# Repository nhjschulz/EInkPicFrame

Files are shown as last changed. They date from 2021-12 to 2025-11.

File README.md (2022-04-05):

# EInkPicFrame

The project builds an electronic picture frame using a 7 color E-Ink display.
It updates after an adjustable time period by reading images from an SD-Card.
The frame is powered from a battery and mimics a real picture frame by requiring
no power cable or a backlight. The software and hardware implements various power
saving methods to run for a long time without recharging.  

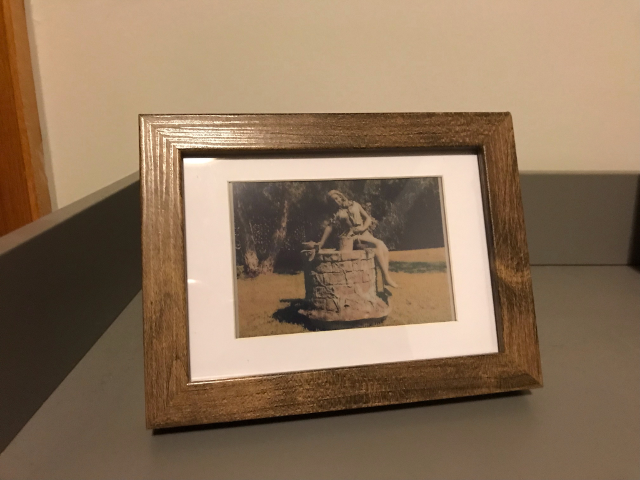
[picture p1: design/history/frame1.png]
Frame One


This is a hobbyist project. I have >20 years background in software development,
but lack the electronic engineering background. I'm using this project to
clear the fog in these mysterious regions below a HAL software layer. The project
therefore includes a hardware design as well.

## Requirements

A set of project requirements is collected here: [Requirements](design/Requirements.md)

## Concept

Block diagram of the system:

Context

## Used Tools

The project is build using open source tools only. All of them are available for free. The following table shows the tools and versions used during development:

|Tool | Usage | Version | Link |
|---|---|---|---|
| Visual Studio Code | Editor and IDE | 1.63.2 | [https://code.visualstudio.com/](https://code.visualstudio.com/) |
| PlatformIO | Software build tools | 5.2.4 | [https://platformio.org/](https://platformio.org/) |
| Python | Script programming | 3.10.1 | [https://www.python.org/](https://www.python.org/) |
| GIMP | Image Manipulation | 2.10.30 | [https://www.gimp.org/](https://www.gimp.org/) |
| ImageMagick | Image Manipulation | 7.1.0 | [https://imagemagick.org/](https://imagemagick.org/) |
| GIT | Version Control | 2.19 | [https://git-scm.com/](https://git-scm.com/) |
| KiCad EDA | Hardware Design | 5.1.12 | [https://www.kicad.org//](https://www.kicad.org/) |

## Software Architecture

The implemented software architecture design is shown on the [Software Architecture](design/SwArchitecture.md) page.

## Hardware

The system is assembled using the following parts: [Partlist](design/Parts.md).

A description of the PCB developed for this project is described
here: [PCB](design/hardware.md).

## Image Generation

The images to show on the frame must be in a special raw format. The process to generate this format is
described on the [ImageConverter](imgconverter/howto.md) page.

## File System

The SD Card must be formated using a FAT file system. The software
expects a folder with the name "epd" on it. This folder contains
the following data:

      [epd]
       |---- [err]
       |---- [img]
       |---- epd.cfg

* The folder "err" holds error images that are displayed in case
  of a problem, like "low battery".
* The folder img holds your images in epd format.
* The file epd.cfg are the parameters for the display. See
  [Parameter File](./design/Parameter.md) for instructions to
  create it.

An example file system can be copied from the example
[File System](./design/FileSystem) folder.

## Prototype Progress

* 2021-12-11: System functional on breadboard (V1 hardware)
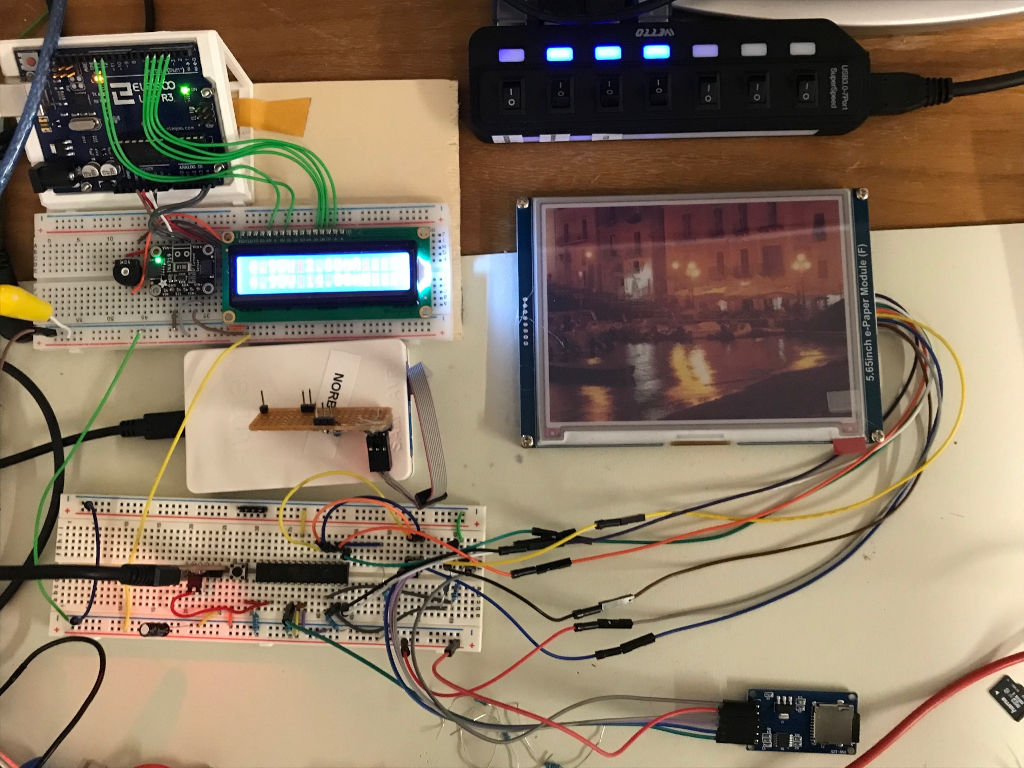
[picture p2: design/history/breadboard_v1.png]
breadboard
  

* 2021-01-22: V1 PCBs arrived and work
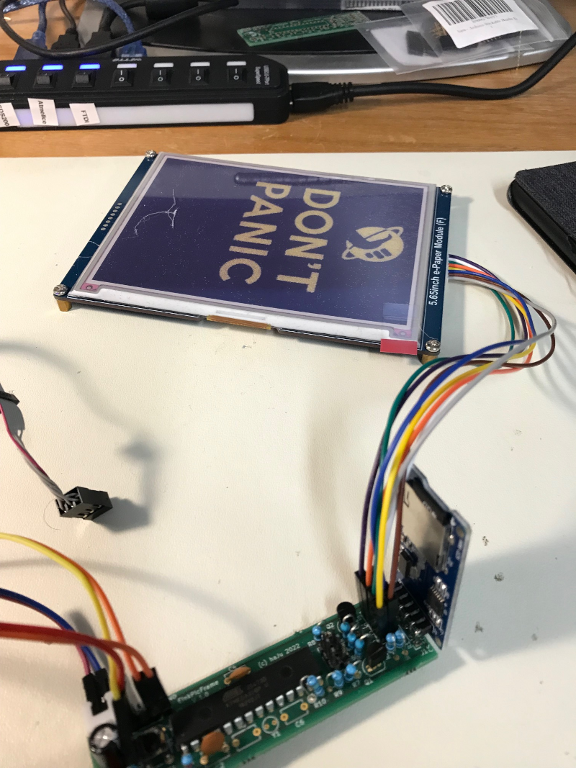
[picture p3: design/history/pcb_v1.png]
PCBv1
  

* 2022-02-01: First frame starts long run test in the living room
  Frame One

  Back side:

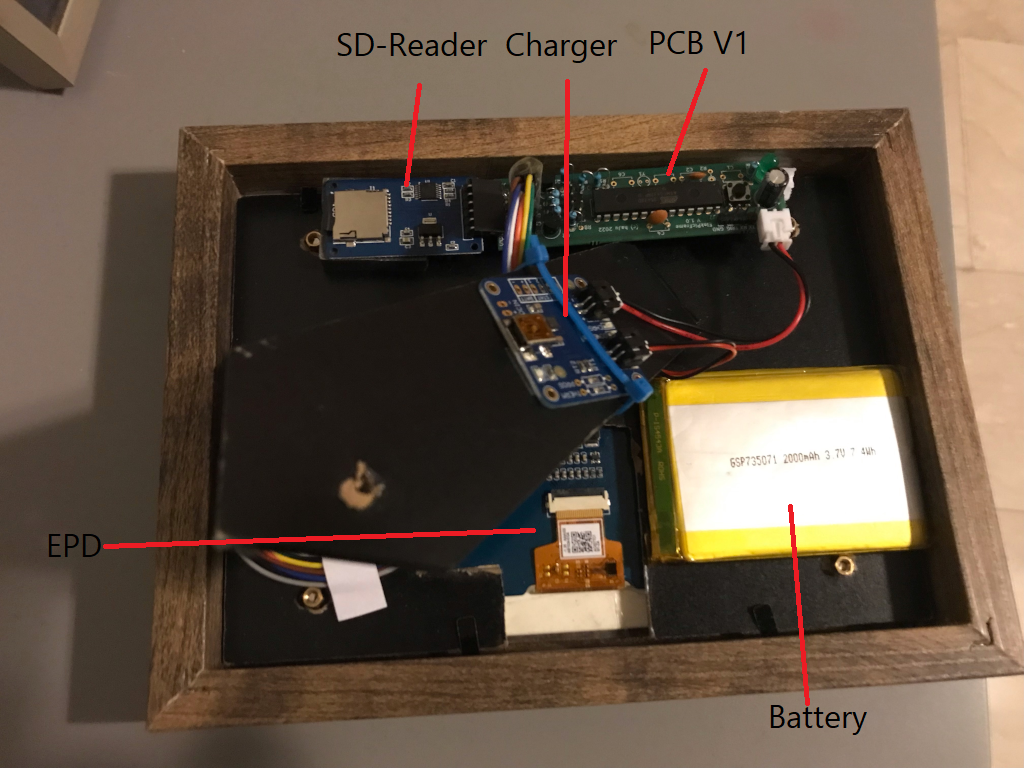
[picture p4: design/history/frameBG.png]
Back


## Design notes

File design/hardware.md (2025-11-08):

# EInkPicFrame Hardware

This page describes the hardware developed for the EinkPicFrame Project.
The current board revision is 1.1. It got designed using KiCAD. The
schematic and pcb project files are in the [hardware](../hw) folder.

The board is deliberately designed to be as small as possible. It's main
purpose is to hide inside a picture frame. It may even get smaller using
SMD parts. I avoided them as I'm realistic regarding my soldering skills.

## Microcontoller AVR 328PU

The heart of the PCB is the AVR 328PU microcontroller. It gives access to
the following capabilities:

* SPI is used for reading from SD-Card, writing to EPD and ISP programming.
* UART TX/RX - Only TX for debug prints is used, RX input is ignored
* A 32.768 kHz watch crystal on the XTAL pins drives Timer2 to wakeup
  the controller from power safe mode.
* ADC voltages - Reference voltage uses the recommended wiring with a capacitor
  and inductor. It is used for measuring the input voltage for low battery
  indication.
* A reset button is connected to restart the system without power cycling.
* PORT C pins are available on a header, but currently unused. They are for
  future extensions.

The pin usage is detailed on the [Pins](Pins.md) page.

## Connectors

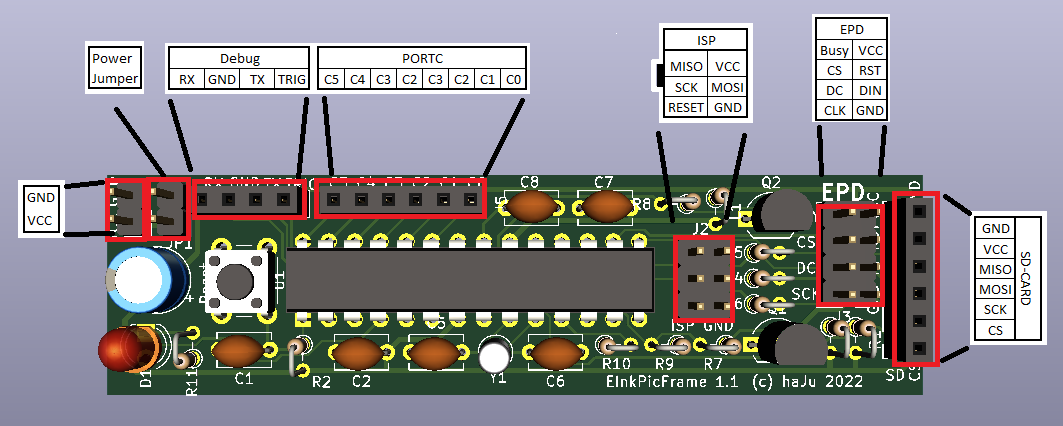
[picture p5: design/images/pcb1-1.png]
Board Connector


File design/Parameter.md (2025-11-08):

# Parameter

EPD supports a parameter file to influence its behavior.
The parameter file is optional. Internal defaults are used
if no parameter block is present in the file system.

## Parameter File

The software expects the parameter file at the following location:

    /epd/epd.cfg

The file is a binary file in the format defined below.
A binary file method was chosen to unburden the microcontroller from
text parsing needs. EPD also offers no user interface for editing
parameter. Producing the parameter set on a PC and store it in the file
system is therefore the easiest solution.

## Paramter File Layout

The contents of the parameter file is a short header, followed by a
sequence of 16 bit values (the parameters) in little endian byte
order (same as on a PC).

### Parameter Header Layout

The parameter header is a sequence of 6 bytes defined below:

             0x00         0x01
          -------------------------
    0x00  |    'E'    |    'P'    |    "EPD" Prefix
    0x02  |    'D'    | <version> |    Parameter record Layout Version (==1)
    0x04  |   <len>   |   <crc>   |    # of Parameter, CRC8 over Parameters
          -------------------------

The used 8-Bit Crc is CRC-8-CCITT with init value 0x00 as defined here:
[https://www.nongnu.org/avr-libc/user-manual/group__util__crc.html](https://www.nongnu.org/avr-libc/user-manual/group__util__crc.html)

### Parmeter Layout (Version 1)

The following table shows the supported parameters:

|Offset| Parameter  | Definiton | Unit | Default |  Range |
|---|---|---|---|---|-----|
| 0x06 | Interval | Update Interval | Minutes | 1440 (1 Day) | 1-65535 |
| 0x08 | MinVoltage | Minimum supply voltage before entering LowBattery mode | MilliVolt | 3300mV | 33000-5000 |
| 0x0A | RefVoltage | Calibrated internal ADC reference voltage.| MilliVolt | 1100mv (BandGap on AVR) | 1000-5000 |
| 0x0C | SupVoltage | Supply voltage on AVCC pin. Only used for RefVoltage calibration| MilliVolt | 5000 | 3300-5000 |

## Creating the Parameter File with epdcfg.py

A Python base tool for generating the parameter binary file based
on JSON is available in the parameter folder.
It generates the parameter data based on the following JSON record:

    {
    "Header" :
        {
            "Version" : 1
        },
    "Parameter" :
        {
            "Interval"   : 1440,
            "MinVoltage" : 3300,
            "RefVoltage" : 1100,
            "SupVoltage" : 5001
        }
    }

Call the tool es follows:

    $ python epdcfg.py param.json
    Reading data from .\param.json

    Interval   : 1440 minutes
    MinVoltage : 3300 mV
    refVoltage : 1100 mV
    supVoltage : 5001 mV
    crc        : 0x42

    Storing configuration into epd.cfg

This process is a little cumbersome. If there is space left for
parsing at the end, I'll probably replace it with a ASCII parser
and a text file approach.

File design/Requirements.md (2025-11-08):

# Project Requirements

The page lists a set of requirements for the design of this project.

## General Requirements

| ID | Requirement |  Comment|
|---|---|---|
| RQ_GEN_01 | The system shall display pictures that are stored onto it.||
| RQ_GEN_02 | The system shall be small enough to be embeddable into a picture frame.||
| RQ_GEN_03 | The system shall advance to a new picture at least once every 24 hours.||
| RQ_GEN_02 | The system shall run with a battery for several month.||
| RQ_GEN_04 | The system shall become and use only OpenSource.||

## Hardware Requirements

| ID | Requirement |  Comment|
|---|---|---|
| RQ_HW_01 | The HW shall consume less than 10uA power when idle||
| RQ_HW_02 | The HW shall consume less than 200mA power when updating the screen||

## Software Requirements

| ID | Requirement |  Comment|
|---|---|---|
| RQ_SW_01 | The SW platform shall be PlatformIO with Visual Studio Code.||
| RQ_SW_02 | The SW shall be programmed in C or C++||
| RQ_SW_03 | The software shall put the system into minimal power consumption mode when no processing is needed. | $1 |

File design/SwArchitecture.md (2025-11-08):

# Software Architecture

This page defines the software architecture of the EPaperFrame.

## Software Context

The software is developed in C/C++ and runs on the AVR328P micro controller. The AVR was chosen because of its easy to solder DIP packaging and builtin power saving modes. The limited amount of RAM (2Kb!) was also an interesting extra SW challenge, given that a single SD-CARD block already needs 25% of it.

The following picture shows the context of the software. The file system and display is controlled using a single SPI interface and two MOSFETs to disable their power in sleep.

The other interfaces are used for flashing (ISP) and debugging (LED, UART) purposes only.

Context

## System State Maschine

The application is a small state machine which toggles between updating the display and sleeping to save power.

Context

## Class Diagram

A typical embedded 3 Layer Architecture is used in this project. Dependencies only go down to lower layers.

Context

### App Layer

This part implements the application logic and utilizes a service layer for interacting with the system.

### Service Layer

This part implements generic services on top of Hal.

### Hal Layer

This part implements the interface to the AVR 328P microcontroller.

## Architecture Rules

* System is static, there is no heap usage or dynamic object generation.
* Classes are implemented as singletons or have only static elements as the system is static.
* Favour many short over fewer large classes (small is beautiful).
* Distribute code phases to states even if they are small (extensibility).
* Save power as much as possible by utilizing sleep modes and unpowering
  unused devices.

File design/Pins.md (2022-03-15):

# PIN assignment

## Pins

The page lists the used pin assignment to/from the microcontroller.

|No| PIN  | Usage | Characteristic |
|--|---|---|---|
| 1| PC6  |  /Reset | input, pullup |
| 2| PD0  | UART RX | UART controlled |
| 3| PD1  | UART TX | UART controlled |
| 4| PD2  | Led | output |
| 5| PD3  | Trigger debug Pin | output |
| 6| PD4  | SDCARD CS | output |
| 7| VCC  | Power | VCC |
| 8| GND  | Power | GND |
| 9| PB6  | watch crystal | 32.768 Khz |
|10| PB7  | watch crystal | 32.768 Khz |
|11| PD5  | SDCARD Mosfet | output |
|12| PD6  | Display Mosfet | output |
|13| PD7  | Display BUSY | input |
|14| PB0  | Display RESET | output |
|15| PB1  | Display DC | output |
|16| PB2  | Display CS | output |
|17| PB3  | SPI MOSI | output |
|18| PB4  | SPI MISO | output |
|19| PB5  | SPI CLK | output |
|20| AVCC | Power | VCC |
|21| AREF | 100nF Capacitor | |
|22| GND  | Power | GND |
|23| PC0  | J15 header | for future use |
|24| PC1  | J15 header | for future use |
|25| PC2  | J15 header | for future use |
|26| PC3  | J15 header | for future use |
|27| PC4  | J15 header | for future use |
|28| PC5  | J15 header | for future use |

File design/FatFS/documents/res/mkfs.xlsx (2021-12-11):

sz_vol [sector] | .fmt = ANY .au_size = 0 |  |  | .fmt = ANY .au_size = 4096 |  |  | .fmt = EXFAT+FAT32 .au_size = 0 |  |  | .fmt = EXFAT .au_size = 0 |  |  | .fmt = FAT32+FAT .au_size = 0 |  |  | .fmt = FAT32 .au_size = 0 |  |  | .fmt = FAT .au_size = 0
 | Type | csize | n_clust | Type | csize | n_clust | Type | csize | n_clust | Type | csize | n_clust | Type | csize | n_clust | Type | csize | n_clust | Type | csize | n_clust
1024 | FAT12 | 1 | 987 | FAT12 | 8 | 123 |  |  |  |  |  |  | FAT12 | 1 | 987 |  |  |  | FAT12 | 1 | 987
1025 | FAT12 | 1 | 988 | FAT12 | 8 | 123 |  |  |  |  |  |  | FAT12 | 1 | 988 |  |  |  | FAT12 | 1 | 988
1026 | FAT12 | 1 | 989 | FAT12 | 8 | 124 |  |  |  |  |  |  | FAT12 | 1 | 989 |  |  |  | FAT12 | 1 | 989
1027 | FAT12 | 1 | 990 | FAT12 | 8 | 124 |  |  |  |  |  |  | FAT12 | 1 | 990 |  |  |  | FAT12 | 1 | 990
1028 | FAT12 | 1 | 991 | FAT12 | 8 | 124 |  |  |  |  |  |  | FAT12 | 1 | 991 |  |  |  | FAT12 | 1 | 991
1029 | FAT12 | 1 | 992 | FAT12 | 8 | 124 |  |  |  |  |  |  | FAT12 | 1 | 992 |  |  |  | FAT12 | 1 | 992
1030 | FAT12 | 1 | 993 | FAT12 | 8 | 124 |  |  |  |  |  |  | FAT12 | 1 | 993 |  |  |  | FAT12 | 1 | 993
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

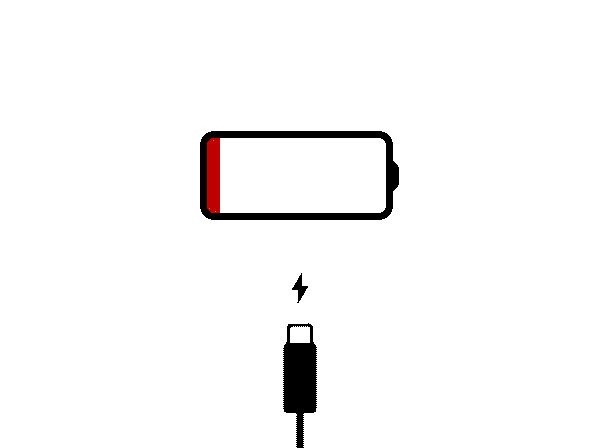
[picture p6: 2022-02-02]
design/images/lb.bmp

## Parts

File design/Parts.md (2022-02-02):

# Used Project Parts

| What |  Decription | Link |
|---|---|---|
| Display| 7-Color E-Ink Display | <https://www.waveshare.com/5.65inch-e-paper-module-f.htm>|
| Processor|MicroChip ATmega328P|<https://ww1.microchip.com/downloads/en/DeviceDoc/Atmel-7810-Automotive-Microcontrollers-ATmega328P_Datasheet.pdf> <https://www.microchip.com/en-us/product/ATmega328p>|
| Micro SD-Card Reader|AZ-Delivery Micro Memory SD TF Card Memory Card Shield Module  |<https://www.az-delivery.de/en/products/copy-of-spi-reader-micro-speicherkartenmodul-fur-arduino>|
|Power Supply| 3.7V LiPo battery |
|Charger|LiPo battery charger and protection circuit|<https://www.adafruit.com/product/259>

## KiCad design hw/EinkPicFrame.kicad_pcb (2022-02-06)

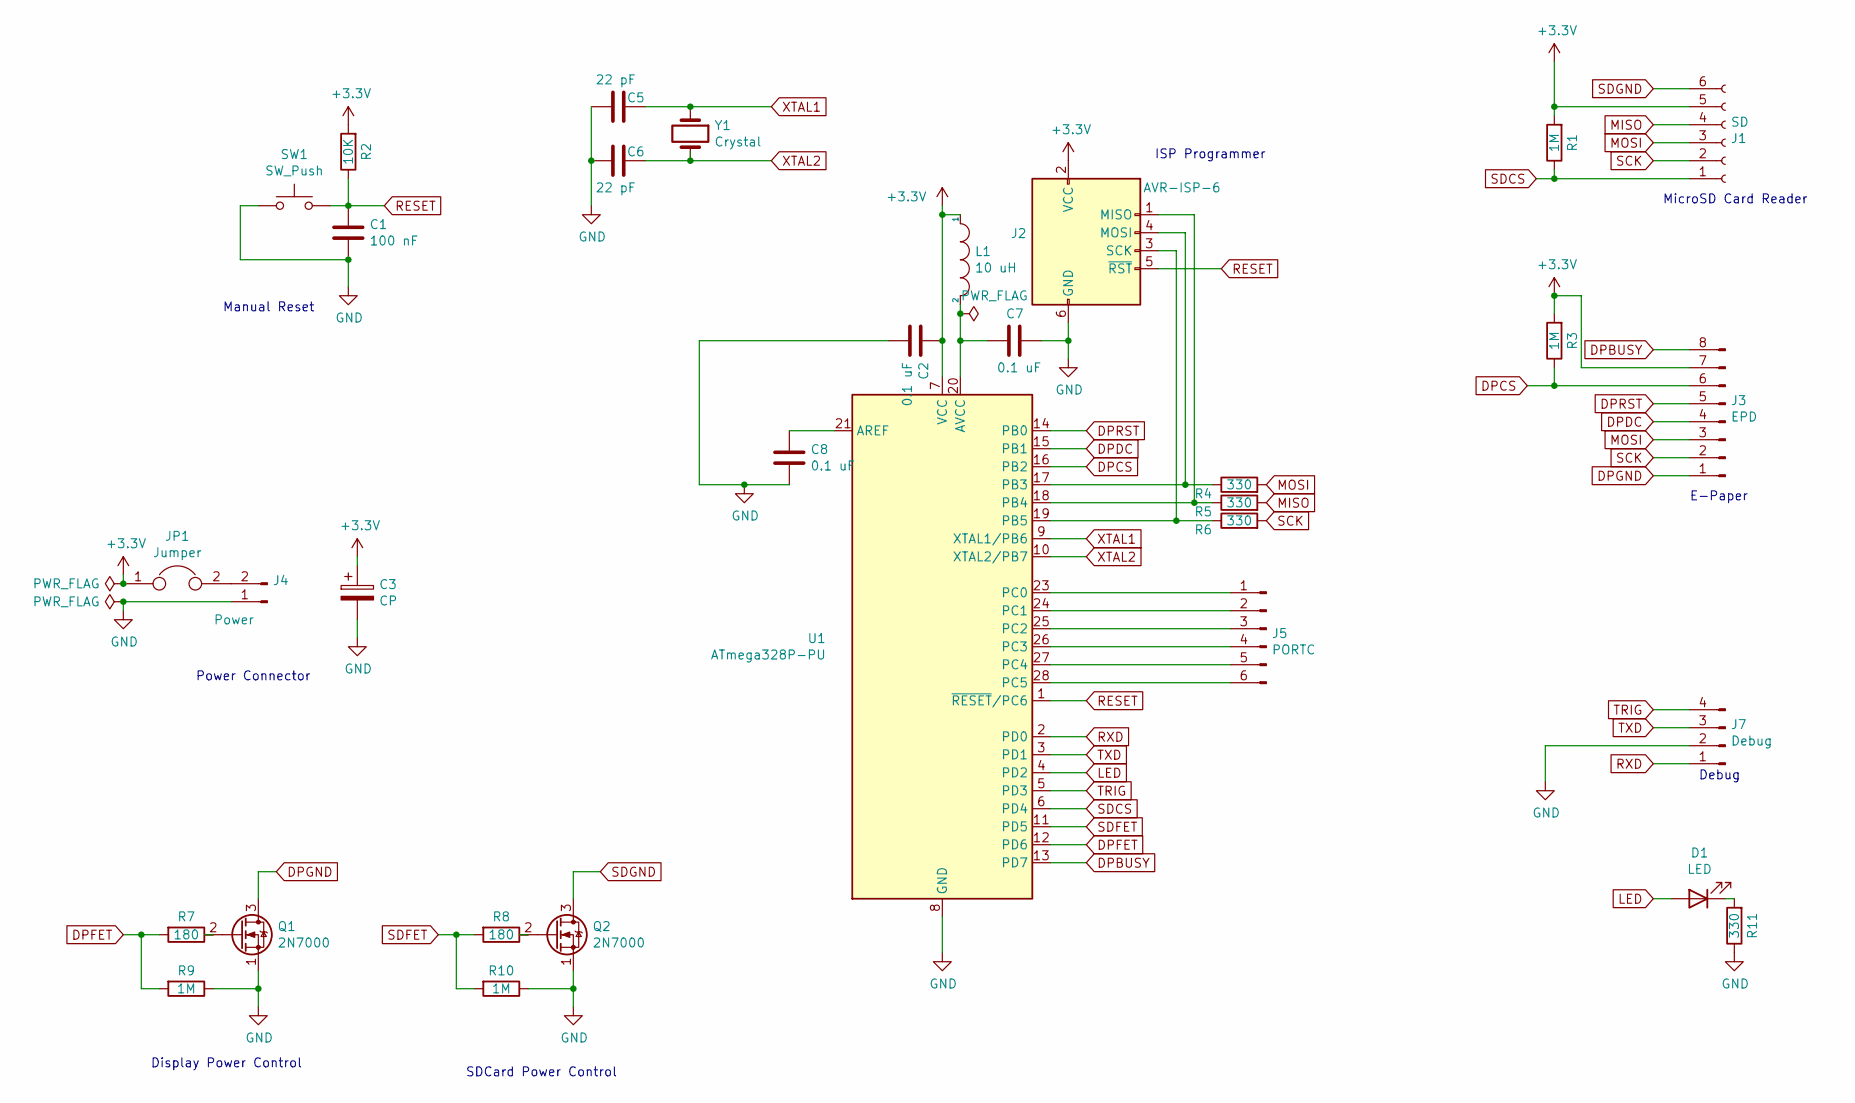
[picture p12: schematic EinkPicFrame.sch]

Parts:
C1: 100 nF; C_Disc_D5.1mm_W3.2mm_P5.00mm
C2, C7, C8: 0.1 uF; C_Disc_D5.1mm_W3.2mm_P5.00mm
C3: CP; CP_Radial_D6.3mm_P2.50mm
C5, C6: 22 pF; C_Disc_D5.1mm_W3.2mm_P5.00mm
D1: LED; LED_D4.0mm
J1: SD; PinSocket_1x06_P2.54mm_Vertical
J2: AVR-ISP-6; PinHeader_2x03_P2.54mm_Vertical
J3: EPD; PinHeader_2x04_P2.54mm_Vertical
J4: Power; PinHeader_1x02_P2.54mm_Vertical
J5: PORTC; PinSocket_1x06_P2.54mm_Vertical
J7: Debug; PinSocket_1x04_P2.54mm_Vertical
JP1: Jumper; PinHeader_1x02_P2.54mm_Vertical
L1: 10 uH; R_Axial_DIN0204_L3.6mm_D1.6mm_P2.54mm_Vertical
Q1: 2N7000; TO-92L_Inline_Wide
Q2: 2N7000; TO-92_Inline_Wide
R1, R3, R9, R10: 1M; R_Axial_DIN0204_L3.6mm_D1.6mm_P2.54mm_Vertical
R2: 10K; R_Axial_DIN0204_L3.6mm_D1.6mm_P2.54mm_Vertical
R4, R5, R6, R11: 330; R_Axial_DIN0204_L3.6mm_D1.6mm_P2.54mm_Vertical
R7, R8: 180; R_Axial_DIN0204_L3.6mm_D1.6mm_P2.54mm_Vertical
SW1: SW_Push; SW_PUSH_6mm
U1: ATmega328P-PU; DIP-28_W7.62mm
Y1: Crystal; Crystal_C38-LF_D3.0mm_L8.0mm_Vertical

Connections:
+3V3: C2.1, C3.1, J1.5, J2.2 (VCC), J3.7, JP1.1, L1.1, R1.2, R2.2, R3.2, U1.7 (VCC)
DPBUSY: J3.8, U1.13 (PD7)
DPCS: J3.6, R3.1, U1.16 (PB2)
DPDC: J3.4, U1.15 (PB1)
DPFET: R7.2, R9.2, U1.12 (PD6)
DPGND: J3.1, Q1.3 (D)
DPRST: J3.5, U1.14 (PB0)
GND: C1.2, C2.2, C3.2, C5.1, C6.1, C7.1, C8.2, J2.6 (GND), J4.1, J7.2, Q1.1 (S), Q2.1 (S), R9.1, R10.1, R11.1, SW1.1, U1.8 (GND), U1.22 (GND)
LED: D1.2 (A), U1.4 (PD2)
MISO: J1.4, R5.2
MOSI: J1.3, J3.3, R4.2
unnamed: C7.2, L1.2, U1.20 (AVCC)
unnamed: C8.1, U1.21 (AREF)
unnamed: D1.1 (K), R11.2
unnamed: J2.1 (MISO), R5.1, U1.18 (PB4)
unnamed: J2.3 (SCK), R6.1, U1.19 (PB5)
unnamed: J2.4 (MOSI), R4.1, U1.17 (PB3)
unnamed: J4.2, JP1.2
unnamed: J5.1, U1.23 (PC0)
unnamed: J5.2, U1.24 (PC1)
unnamed: J5.3, U1.25 (PC2)
unnamed: J5.4, U1.26 (PC3)
unnamed: J5.5, U1.27 (PC4)
unnamed: J5.6, U1.28 (PC5)
unnamed: Q1.2 (G), R7.1
unnamed: Q2.2 (G), R8.1
RESET: C1.1, J2.5 (~RST), R2.1, SW1.2, U1.1 (~RESET~/PC6)
RXD: J7.1, U1.2 (PD0)
SCK: J1.2, J3.2, R6.2
SDCS: J1.1, R1.1, U1.6 (PD4)
SDFET: R8.2, R10.2, U1.11 (PD5)
SDGND: J1.6, Q2.3 (D)
TRIG: J7.4, U1.5 (PD3)
TXD: J7.3, U1.3 (PD1)
XTAL1: C5.2, U1.9 (XTAL1/PB6), Y1.1
XTAL2: C6.2, U1.10 (XTAL2/PB7), Y1.2

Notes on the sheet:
MicroSD Card Reader
E-Paper
ISP Programmer
Manual Reset
Display Power Control
SDCard Power Control
Power Connector
Debug

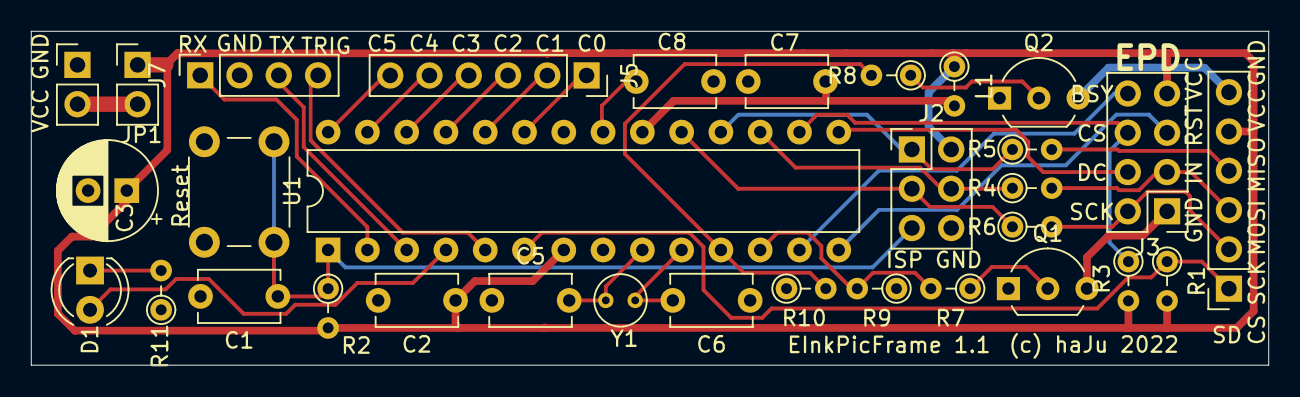
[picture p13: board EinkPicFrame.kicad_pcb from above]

Board: 2 copper layers, 80.0 x 21.6 mm, 32 parts (0 on the bottom side), 36 nets.

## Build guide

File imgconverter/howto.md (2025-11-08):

# Image Converter How-To

- [Image Converter How-To](#image-converter-how-to)
  - [Image Manipulation With GIMP](#image-manipulation-with-gimp)
    - [Resizing the Image](#resizing-the-image)
    - [Dithering the Image](#dithering-the-image)
      - [Installing the Color Palette](#installing-the-color-palette)
      - [Floyd-Steinberg Dithering](#floyd-steinberg-dithering)
  - [Image Manipulation with ImageMagick](#image-manipulation-with-imagemagick)
    - [Dithering with ImageMagick](#dithering-with-imagemagick)
  - [Creating Display Raw Data](#creating-display-raw-data)
      - [Script Setup](#script-setup)
      - [Script Execution](#script-execution)

This document explains image data generation for the Waveshare 5.65inch e-Paper Module. The process has 2 major steps:

  1. Resize and dithering of the image using GIMP
  2. Converting the image into the e-Paper memory format

As an alternative to GIMP I also recommend to look at
[ImageMagick](https://imagemagick.org/index.php) as an
alternative. ImageMagick is a command line tool, allowing
to process a large number of images using scripts or
typed commands.
## Image Manipulation With GIMP

This chapter explains the steps to create images with the right size and
color palette. The GIMP version used for this How-To was 2.10.30.

### Resizing the Image

The image must have the exact size of 600x448 pixels. The can be done using
the *Scale Image* tool from menu:

    Image / Scale Image...

Enter the following values in the "Scale Image" Dialog:

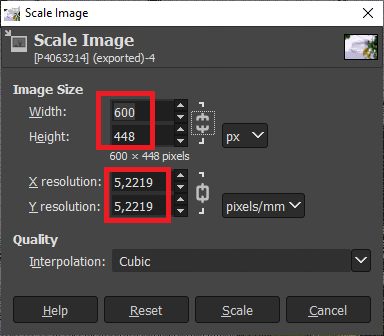
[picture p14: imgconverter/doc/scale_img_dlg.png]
Scale


Press "Scale" to resize the image. You may experiment with various "Interpolation" options in order to figure out what works best.

### Dithering the Image

The next step is to convert the image to the reduced color palette of the e-Paper Module using Floyd-Steinberg dithering.

#### Installing the Color Palette

This step needs to be done only once for a GIMP installation. It adds the e-paper color palette to the list of available palettes.

 1. Open the Palettes Dialog in Gimp from menu

        Window / Dockable Dialogs / Palettes

 2. Right click in the Palettes window and select *Import Palette ...*
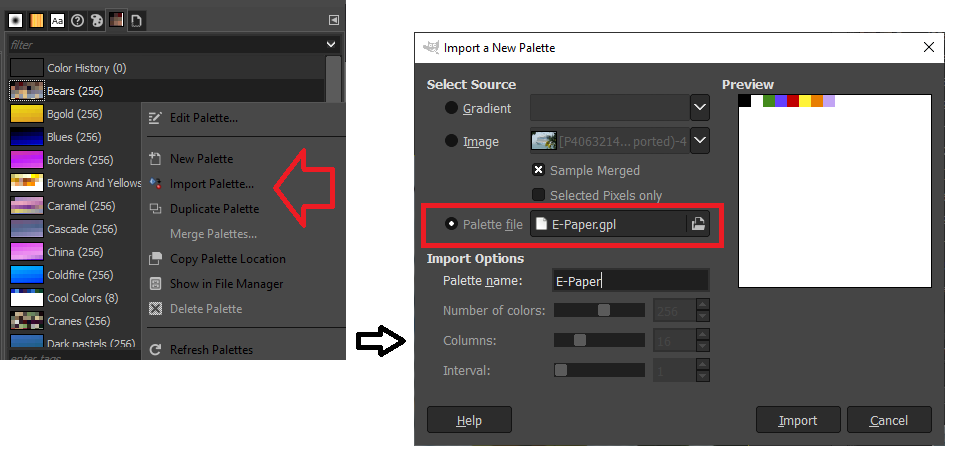
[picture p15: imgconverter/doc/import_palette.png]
Import Palette
    

    Use the palette file from [doc/E-Paper.gpl](doc/E-Paper.gpl).

Now the palette is available in the palettes list:

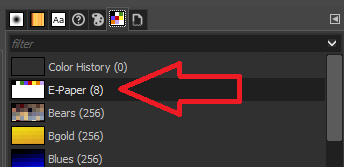
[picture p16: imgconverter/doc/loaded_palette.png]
Imported Palette


Note: This palette has 8-Colors defined, but the display only supports  7. But there is indeed an additional one for "cleaning". It means no ink visible and is intended to wipe the pixels between changing images. It  avoids ghosting, but is also a color at the end. The following picture shows the 8 palette colors:

Colors

#### Floyd-Steinberg Dithering

This Floyed-Steinberg dithering algorithm converts images to look still good using a reduced color set. In GIMP this algorithm gets applied by converting an image to *Indexed Colors Mode*. The pixels then contain an index into a color palette instead of RGB values.

  1. Switch the image to indexed mode by using menu

          Image / Mode / Indexed...

  2. The *Indexed Color Conversion* dialog appears

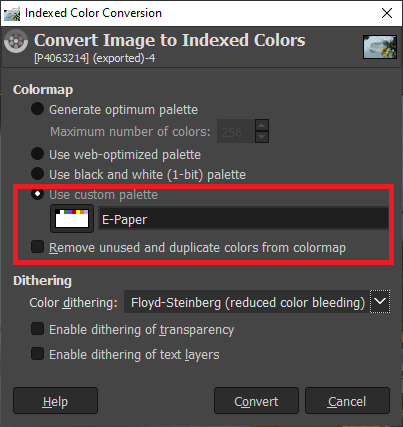
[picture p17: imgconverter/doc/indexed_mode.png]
Indexed Colors Dialog
     

  3. Select our *Custom E-paper Palette"

  4. Make sure that "Remove unused and duplicate colors..." is NOT checked. We need to keep the palette indexes as they are.

  5. Select a dithering algorithm. You may try different ones to see what works best in your case.

  6. Export the result as Windows BMP file using menu

          File / Export As...

  Select "Windpws BMP Image" from the "Select File Type" list.

## Image Manipulation with ImageMagick

ImageMagick is like a swiss army knife for image manipulation.
It is a commandline tool with a wealth of options.I don't
recommend to change the image size to 600x448 by script
(also it is perfectly doable with this tool). Each image has
different resize needs (What part of it, what aspect ratio ...).
But dithering is incredibly easy to do on a single or set of files.

### Dithering with ImageMagick

ImageMagick support the -dither option, which is
basically all you need. The only obstacle is that you
need to pass the color palette via an image using the palette
already. This smells a little like a chicken or egg issue. You
can create such an image using the GIMP method described in this
file, or use the [palette colors image](doc/colors.png). It is
already an indexed picture with the right colors.

The call to dither an image is then this:

    magick convert input.jpg -dither FloydSteinberg -remap colors.png output.png

You need to specify the full path to colors.png, unless it is in
the current working directory as well.

The following command will dither **all** files with.jpg extension
into Png files with the same filename:

    magick convert *.jpg -dither FloydSteinberg -remap colors.png -set filename:base "%[basename]" "%[filename:base].png"

## Creating Display Raw Data

The proper sized and dithered image must be converted one more time into the
display memory raw format. This is a simple byte stream of color index values.
Each byte holds two index values, one in the upper 4 bit, the following in the
lower 4 bit.

A python script for converting the images into this raw format is available
[here](./epdconv.py).

#### Script Setup

The script needs a Python 3.x environment with
[Pillow](https://pillow.readthedocs.io/en/stable/index.html). Pillow can be
installed using pip:

    python -m pip install --upgrade pip
    python -m pip install --upgrade Pillow

#### Script Execution

Simply call the Python script with one or more image files as arguments.

    python epdconv.py img000.bmp imgage001.bmp ...

It will create the raw display image files with the same filename and
a ".epd" (E-Paper Display) extension on success.

The script does some sanity checks regarding size and color index mode.
Unfit image will be skipped with a warning.

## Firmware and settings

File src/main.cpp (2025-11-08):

/*
 * BSD 3-Clause License
 *
 * Copyright (c) 2021, Norbert Schulz
 * All rights reserved.
 *
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
 * 3. Neither the name of the copyright holder nor the names of its
 *    contributors may be used to endorse or promote products derived from
 *    this software without specific prior written permission.
 *
 * THIS SOFTWARE IS PROVIDED BY THE COPYRIGHT HOLDERS AND CONTRIBUTORS "AS IS"
 * AND ANY EXPRESS OR IMPLIED WARRANTIES, INCLUDING, BUT NOT LIMITED TO, THE
 * IMPLIED WARRANTIES OF MERCHANTABILITY AND FITNESS FOR A PARTICULAR PURPOSE ARE
 * DISCLAIMED. IN NO EVENT SHALL THE COPYRIGHT HOLDER OR CONTRIBUTORS BE LIABLE
 * FOR ANY DIRECT, INDIRECT, INCIDENTAL, SPECIAL, EXEMPLARY, OR CONSEQUENTIAL
 * DAMAGES (INCLUDING, BUT NOT LIMITED TO, PROCUREMENT OF SUBSTITUTE GOODS OR
 * SERVICES; LOSS OF USE, DATA, OR PROFITS; OR BUSINESS INTERRUPTION) HOWEVER
 * CAUSED AND ON ANY THEORY OF LIABILITY, WHETHER IN CONTRACT, STRICT LIABILITY,
 * OR TORT (INCLUDING NEGLIGENCE OR OTHERWISE) ARISING IN ANY WAY OUT OF THE USE
 * OF THIS SOFTWARE, EVEN IF ADVISED OF THE POSSIBILITY OF SUCH DAMAGE.
 */

#include "app/StateHandler.h"

#if WITH_POWER_TEST != 0

#include "app/PowerTestState.h"

/** Power consumption testing state
 */
static app::StateHandler g_stateHandler(app::PowerTestState::instance());

#else

#include "app/InitState.h"

/** State machine object
 *
 * Initial state is the InitState instance.
 */
static app::StateHandler g_stateHandler(app::InitState::instance());
#endif

int main(int argc, char** argv)
{
    (void)argc;
    (void)argv;

    /* run state machine forever */
    for(;;)
    {
        g_stateHandler.process();
    }

    return 0;
}

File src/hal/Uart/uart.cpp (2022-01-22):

/*
 * BSD 3-Clause License
 * 
 * Copyright (c) 2021, Norbert Schulz
 * All rights reserved.
 * 
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
 * 3. Neither the name of the copyright holder nor the names of its
 *    contributors may be used to endorse or promote products derived from
 *    this software without specific prior written permission.
 * 
 * THIS SOFTWARE IS PROVIDED BY THE COPYRIGHT HOLDERS AND CONTRIBUTORS "AS IS"
 * AND ANY EXPRESS OR IMPLIED WARRANTIES, INCLUDING, BUT NOT LIMITED TO, THE
 * IMPLIED WARRANTIES OF MERCHANTABILITY AND FITNESS FOR A PARTICULAR PURPOSE ARE
 * DISCLAIMED. IN NO EVENT SHALL THE COPYRIGHT HOLDER OR CONTRIBUTORS BE LIABLE
 * FOR ANY DIRECT, INDIRECT, INCIDENTAL, SPECIAL, EXEMPLARY, OR CONSEQUENTIAL
 * DAMAGES (INCLUDING, BUT NOT LIMITED TO, PROCUREMENT OF SUBSTITUTE GOODS OR
 * SERVICES; LOSS OF USE, DATA, OR PROFITS; OR BUSINESS INTERRUPTION) HOWEVER
 * CAUSED AND ON ANY THEORY OF LIABILITY, WHETHER IN CONTRACT, STRICT LIABILITY,
 * OR TORT (INCLUDING NEGLIGENCE OR OTHERWISE) ARISING IN ANY WAY OUT OF THE USE
 * OF THIS SOFTWARE, EVEN IF ADVISED OF THE POSSIBILITY OF SUCH DAMAGE.
 */
#include "Uart.h"

#include <avr/io.h>
#include <avr/pgmspace.h>
#include <avr/interrupt.h>
#include <avr/power.h>
#include <util/delay.h>

/** UART driver for the AVR328P USART in asynchronous mode
 */
namespace hal
{
    /** UART singleton instance
     */
    Uart Uart::m_instance;

    /** Baudrate configuration values
     */
    static const struct BaudrateSettings
    {
        uint8_t high;   /**< High byte   */
        uint8_t low;    /**< Low byte    */
        uint8_t u2x;    /**< U2X to set? */
    
    } regBaudrate[Uart::BAUD_INVALID] PROGMEM =
    {
        #define BAUD    2400
        #include <util/setbaud.h>
            {   UBRRH_VALUE, UBRRL_VALUE, USE_2X    },
        #undef BAUD

        #define BAUD    4800
        #include <util/setbaud.h>
            {   UBRRH_VALUE, UBRRL_VALUE, USE_2X    },
        #undef BAUD

        #define BAUD    9600
        #include <util/setbaud.h>
            {   UBRRH_VALUE, UBRRL_VALUE, USE_2X    },
        #undef BAUD

#if F_CPU > 1000000

        #define BAUD    14400
        #include <util/setbaud.h>
            {   UBRRH_VALUE, UBRRL_VALUE, USE_2X    },
        #undef BAUD

        #define BAUD    19200
        #include <util/setbaud.h>
            {   UBRRH_VALUE, UBRRL_VALUE, USE_2X    },
        #undef BAUD
#endif
#if F_CPU > 4000000
        #define BAUD    28800
        #include <util/setbaud.h>
            {   UBRRH_VALUE, UBRRL_VALUE, USE_2X    },
        #undef BAUD

        #define BAUD    38400
        #include <util/setbaud.h>
            {   UBRRH_VALUE, UBRRL_VALUE, USE_2X    },
        #undef BAUD

        #define BAUD    57600
        #include <util/setbaud.h>
            {   UBRRH_VALUE, UBRRL_VALUE, USE_2X    },
        #undef BAUD

        #define BAUD    76800
        #include <util/setbaud.h>
            {   UBRRH_VALUE, UBRRL_VALUE, USE_2X    },
        #undef BAUD

        #define BAUD    115200
        #include <util/setbaud.h>
            {   UBRRH_VALUE, UBRRL_VALUE, USE_2X    },
        #undef BAUD

        #define BAUD    234000
        #include <util/setbaud.h>
            {   UBRRH_VALUE, UBRRL_VALUE, USE_2X    },
        #undef BAUD

        #define BAUD    250000
        #include <util/setbaud.h>
            {   UBRRH_VALUE, UBRRL_VALUE, USE_2X    },
        #undef BAUD
        
    #endif
    };

    /** Parity register bit settings in UCSR0C
    */
    static const uint8_t regParityBits[Uart::PARITY_INVALID] PROGMEM =
    {
        (0 << UPM01) | (0 << UPM00), // Uart::PARITY_NONE
        (1 << UPM01) | (0 << UPM00), // Uart::EVEN
        (1 << UPM01) | (1 << UPM00), // Uart::ODD
    };

    /** Stop bit settings in UCSR0C
    */
    static const uint8_t regStopBits[Uart::STOPBIT_INVALID] PROGMEM =
    {
        (0 << USBS0),    // Uart::STOPBIT_1
        (1 << USBS0)     // Uart::STOPBIT_2
    };

    Uart::Uart() :
        m_isOpen(false),
        m_cfg()
    {
    }

    Uart::~Uart()
    {
    }

    Uart::RetVal Uart::open(const Uart::Cfg& cfg)
    {
        if (m_isOpen)
        {
            return RET_OPENALREADY;
        }

        uint8_t localUCSR0A(UCSR0A);
        uint8_t localUCSR0B(UCSR0B);
        uint8_t localUCSR0C(UCSR0C);

        /* Hardcode data width to 8 bit, never seen anything else ... 
         */
        localUCSR0C |= (_BV(UCSZ01) | _BV(UCSZ00));
        localUCSR0B &= ~_BV(UCSZ02);
        

        /* Configure parity mode */
        if (cfg.m_parity < Uart::PARITY_INVALID)
        {
            localUCSR0C &= ~(_BV(UPM01) | _BV(UPM00));
            localUCSR0C |= pgm_read_byte(&regParityBits[cfg.m_parity]);
        }
        else
        {
            return RET_INVPARAM;
        }

        /* Configure stopbits
         */
        if (cfg.m_parity < Uart::PARITY_INVALID)
        {
            localUCSR0C &= ~_BV(USBS0);
            localUCSR0C |= pgm_read_byte(&regStopBits[cfg.m_stopBits]);
        }
        else
        {
            return RET_INVPARAM;
        }

        /* Configure baudrate
         */
        if (cfg.m_baudRate < Uart::BAUD_INVALID)
        {
            if (0 == pgm_read_byte(&regBaudrate[cfg.m_baudRate].u2x))
            {
                localUCSR0A &= ~_BV(U2X0);
            }
            else
            {
                localUCSR0A |= _BV(U2X0);
            }
        }
        else
        {
            return RET_INVPARAM;
        }

        /* Enable transitter / receiver based on mode
         */
        localUCSR0B &= ~(_BV(RXEN0) | _BV(TXEN0) | _BV(RXCIE0) | _BV(UDRIE0));
        switch(cfg.m_mode)
        {
            case MODE_READ:
                if (nullptr == cfg.m_inputQ)
                {
                    return RET_INVPARAM;
                }
                cfg.m_inputQ->clear();

                localUCSR0B |= (_BV(RXEN0) | _BV(RXCIE0));
                break;

            case MODE_WRITE:
                if (nullptr == cfg.m_outputQ)
                {
                    return RET_INVPARAM;
                }
                cfg.m_outputQ->clear();

                localUCSR0B |= _BV(TXEN0);
                break;
            
            case MODE_READWRITE:
                if ((nullptr == cfg.m_inputQ) || (nullptr == cfg.m_outputQ))
                {
                    return RET_INVPARAM;
                }
                cfg.m_inputQ->clear();
                cfg.m_outputQ->clear();

                localUCSR0B |= (_BV(RXEN0) | _BV(TXEN0) | _BV(RXCIE0));
                break;
            
            case MODE_INVALID:
            default:
                return RET_INVPARAM;
                break;
        }

        m_cfg = cfg;
        m_isOpen = true;

        power_usart0_enable();
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

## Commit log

2021-12-09 AVR SW environment setup
    * Atmel ICE programming in ISP mode working
    * "Blinky" app working on breadboard (LED on PB0)
2021-12-11 Added FatFS distribution to service layer
    Version R0.14.b from http://elm-chan.org/fsw/ff/00index_e.html
    [mkfs.xlsx]
2021-12-18 UART: Added driver
    Added UART driver which will support debug logs in future.
2021-12-19 Debug: Added printf style debug over UART
2021-12-19 FatFS: Moved documentation from src to design
    [mkfs.xlsx]
2021-12-20 SPI: Add initial driver version
2021-12-21 Ticktimer: Inititial implementation
    User Timer0 to implement a 10ms tick timer.
2021-12-28 SpI: Added byte order ans pflash data support
2021-12-28 Debug: Fixed cpp vararg part
    Variable part now optional to allow printf style call with format only.
2021-12-28 Display: Added Driver code
    Init, Sleep and Clear are working.
2021-12-31 FatFS: Checkpoint 1st working version
    TODOs:
    * Interface with SPI diver (code manipulates register directly)
    * Coexistence with display SPI
2021-12-31 HW: Addind Pin assignment definition
2021-12-31 SPI: Support bot SDCard an Display
    Reconfigure SPI to a slave on each IO of this slave.
2022-01-01 HW: Started schematic with KiCad
    [EinkPicFrame.kicad_pcb, EinkPicFrame.sch]
2022-01-02 HW: Created PCB
    [EinkPicFrame.kicad_pcb, EinkPicFrame.sch]
2022-01-03 HW: Added possibility to add a crystal
    [EinkPicFrame.kicad_pcb, EinkPicFrame.sch]
2022-01-05 Service: Introduce Power cladd
2022-01-05 Service: Fixed searcg/replace for Gpio access
    "set" functions got turned into "clr" by accident.
    [Display.cpp]
2022-01-06 HAL: Add Wakeup timer Timer2 driver to wakeup from power down mode
2022-01-06 Doc: Added Power handling classes
2022-01-06 Service: Added APIs to control module powering
    SD Card and Display can be powered by Mosfets
2022-01-06 Service: Added Debug api for trigger pin
2022-01-08 HAL: UART Drain TX buffer before disabling
2022-01-08 HAL: Add power up/down to SPI
2022-01-08 HAL: Start with onchip peripherals powered off
2022-01-09 HAL: Add enable/disable power to TickTimer
2022-01-09 HAL: enable SPI 2X mode
    We only run a 1Mhz, so double speed should not be an issue.
    [Spi.cpp]
2022-01-09 Service: Mocved power related code to Power class
2022-01-12 SPI: Tune Gpios for lowest power when off
2022-01-12 App: Move power resume to init state
    Service Init only sets default gpio state.
2022-01-12 App: Move display init to update state
    Was in power resume, but this does only enable onchip devices, not the display.
2022-01-14 App: Added power consumption test code
    Enable with -D WITH_POWER_TEST=1
2022-01-14 Cpu: Implement nonbusy delay function
    Function is called as Cpu::idle(x), where x is number of 10ms timer ticks
2022-01-16 Hal: Set GPIO high/low before switching direction
    Avoids short glitches on chipselect lines
    [Gpio.cpp]
2022-01-16 Service: User power frindly sleep in display
2022-01-16 service: Added LED access
2022-01-16 service: Added idle() wait to Power class
2022-01-16 App: Blink Led as start indicator in initstate
2022-01-16 build: Ignore assembler listing file by git
2022-01-16 Cpu: Increase fast clock to 4 Mhz
    Increasig from 1 to 4 Mhz doesn't consume much more CPU current
    when busy. But it reduces SD-Card
    busy time from 12 to 4 seconds.
    [TickTimer.cpp]
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2022-01-19 HW: Ubgrade to KiCad 6.0
    Jut open project in Kicad 6 and save to new format.
    [EinkPicFrame.kicad_pcb, EinkPicFrame.kicad_sch]
2022-01-22 HAL: Add API to change SPI clock frequency
2022-01-22 HAL: Introduce HW revision
    Prepare switch from N-Mosfets to P-Mosfets for contolling power.
2022-01-22 Service: Set SPI clock to max for display IO
2022-01-22 Service: Fix SDCard init issue
    Repeate sending CMD0 for up to 10 times. Many cards don't respond on the first try.
    Don't wait for card ready
    in CMD0 case. Some cards
    don't signal it during init
    stage.
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2022-01-29 HAL: Get down to >100 nA by driving IOs high
    IO's to SD and EPD need to be high during sleep.
    Otherwise current flows over the IOs as the FETs are
    low side switches.
    Current need dropped from 800 nA to < 100nA, which
    I cannot really measure anymore.
2022-01-30 HW: Revert to KiCad 5
    I have trouble getting 3d view to work wiht KiCad 6
    [EinkPicFrame.kicad_pcb, EinkPicFrame.kicad_sch]
2022-01-30 APP: Support Parameter file
    Add support for a parameter file to modify settings
    like the picture update interval and voltage settings.
2022-02-01 App: Add LowPower state
    Check supply voltage in init and when leaving sleep.
    Enter lowPower mode if voltage is below the minimum
    voltage parameter level.
    The LowPower state displays a charge image and
    keeps sleeping until voltage raised above the
    minimum again.
2022-02-02 FILESYS: Added skeleton
    EPD expects a a epd folder with specific subfolders on
    the SD card. Added a folder with an example how it has to be setup.
    [epd.cfg]
2022-02-02 Doc: Updated readme showing 1st build picture frame
2022-02-06 HW: ADC + Small improvements (V1.1)
    Added proper wiring for AVCC and AREF according to data sheet
    * 100 nF capacitor to ground on AREF
    * 10 uH inductor on AVCC
    Added header for unused PortC pins
    * May be used as 2nd SPI (bit bang)
    * Independent SPI would allow to power EPD and SD independently
    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
    [EinkPicFrame.kicad_pcb, EinkPicFrame.sch]
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2022-02-13 App: Improve error handling
    * Detect missing EPD by having timeouts on init (no hang forever)
    * Blink LED 10 times on EPD error
    * Display red screen if EPD responsive during an error
    * Power down system after error display on screen or led
    [Display.cpp]
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2022-02-24 HAL: Drive wakeup timer from external crystal
    Change Timer2 (Wakeup timer) to run asynchronously from a 32.768 kHz
    crystal. This allows the CPU to really enter power safe mode.
    Aleep current dropped from 100 uA (5v) to something I cannot measure
    anymore.
2022-03-03 ErrorState: Enable display power for red screen
    Display must be powered to switch to red error screen.
2022-03-06 Power: Rework sleep power handling
    Keep SD and Display power in sync
    * Both use the same SPI signal lines
    * Disabling only one cause current draw of IO lines when low
    Improve time management
    * add millis counter to TickTimer
    * compensate sleep durations in tick counter when timer is stopped
    * Further accuracy improvements pending
    Use Fat32 volume serial to detect card swaps
    * check after sleep if card is still the same
    * reinit on swaps
    [Power.cpp]
2022-03-15 Design: Document pins uses for watch crystal
    The crystal is needed for power safe mode.
    Internal clock otherwise keeps running in power safe mode.
2022-03-15 TickTimer: Improve accuracy
    10ms is is 156.25 interrupts at 4 Mhz CPU.
    Count 1 cycle more every 4 cycles.
2022-03-19 Power: Low Battery state fixes
    Debugging low battery detection using an
    adjustable power supply showed to issues
    * Integer overflow computing milliseconds for 10min duration
    Math was done using 16bit, needed to add ul suffix to force 32bit
    * Reassignment to a reference variable is not working. Use pointer
    instead
    Strange that no compiler warnings where generated by this issues.
2022-04-02 Sleep: Fix sleep loops calculation
    Ensure milliseconds are computed in 32 bits to avoid overflows.
2022-04-03 Add SD-CARD change detection
    Compare volume serial number at wakeup with the one read at startup.
    Reset system if card was swapped.
    [Power.cpp]
